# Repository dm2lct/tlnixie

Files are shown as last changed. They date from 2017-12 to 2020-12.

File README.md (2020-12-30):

# Schematics and PCB files for the Turmlabor nixie clock kit. 
# Attention: This is a old, buggy version! See the new design on https://github.com/ludwig1992/Nixieclock_kit

Feel free to build your own nixie clock from it.

Features:
  - IN14 nixie tubes but you can adapt many other nixie tubes even if it would not look great
  - ESP12e controller so you can make IoT with it and build your own botnet for world domination if you have enough clocks
  - DS3231 RTC for everyone who does not like IoT and does also not want to be enslaved from AI
  - WS2812B under each nixie tube to make them look more fancy
  - runs from a simple USB charger
  - you can program the controller with your Arduino IDE over USB

But in this version there are a few known issues:

  - wrong footprint of U201 and U202, it should be PQFP44, but of any reason we put TQFP44 on this board. You can solder it but it's not fun. 
  - wrong wiring of U403, you need to wire pin 10 and 11 to pin 18 and 19 and move VCC from pin 18 to pin 20.
  - the high voltage power supply does not work as good as it is supposed to be. This might be a problem with the low input voltage of about 5V

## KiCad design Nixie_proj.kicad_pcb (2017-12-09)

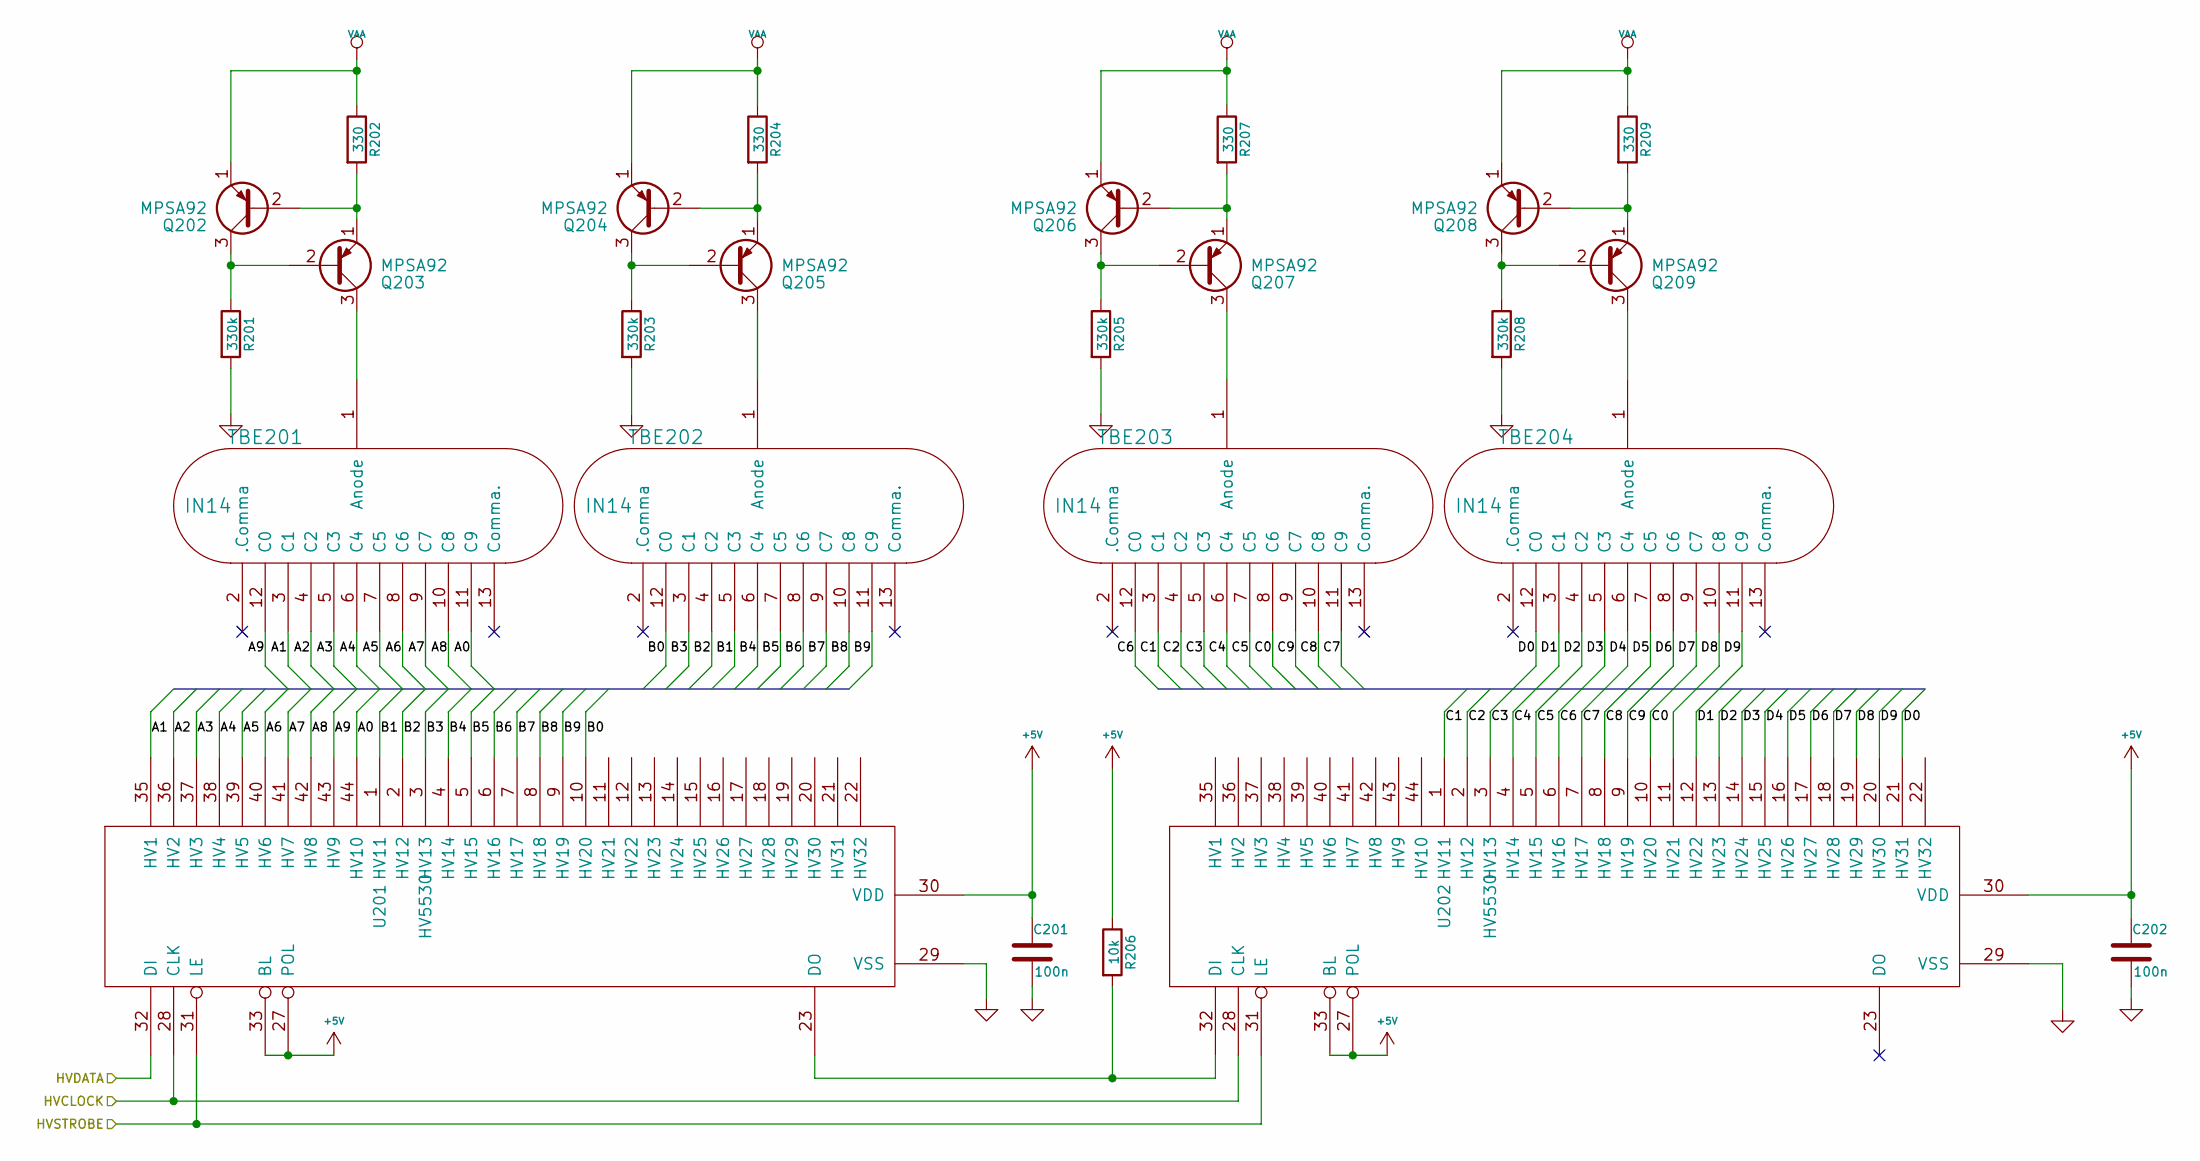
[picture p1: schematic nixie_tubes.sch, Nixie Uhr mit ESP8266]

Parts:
C201, C202: 100n; C_0805_HandSoldering
Q202, Q203, Q204, Q205, Q206, Q207, Q208, Q209: MPSA92; TO-92_Molded_Wide_Oval
R201, R203, R205, R208: 330k; R_Axial_DIN0207_L6.3mm_D2.5mm_P10.16mm_Horizontal
R202, R204, R207, R209: 330; R_Axial_DIN0207_L6.3mm_D2.5mm_P10.16mm_Horizontal
R206: 10k; R_0805_HandSoldering
TBE201, TBE202, TBE203, TBE204: IN14; IN-14-mod
U201, U202: HV5530; TQFP-44_10x10mm_Pitch0.8mm

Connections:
+5V: C201.1, C202.1, R206.1, U201.27 (POL), U201.30 (VDD), U201.33 (BL), U202.27 (POL), U202.30 (VDD), U202.33 (BL); also elsewhere on the board
/Microcontroller and clock/HVCLOCK: U201.28 (CLK), U202.28 (CLK); also elsewhere on the board
/Microcontroller and clock/HVDATA: U201.32 (DI); also elsewhere on the board
/Microcontroller and clock/HVSTROBE: U201.31 (LE), U202.31 (LE); also elsewhere on the board
/Tubes with drivers/A0: TBE201.11 (C9), U201.44 (HV10)
/Tubes with drivers/A1: TBE201.3 (C1), U201.35 (HV1)
/Tubes with drivers/A2: TBE201.4 (C2), U201.36 (HV2)
/Tubes with drivers/A3: TBE201.5 (C3), U201.37 (HV3)
/Tubes with drivers/A4: TBE201.6 (C4), U201.38 (HV4)
/Tubes with drivers/A5: TBE201.7 (C5), U201.39 (HV5)
/Tubes with drivers/A6: TBE201.8 (C6), U201.40 (HV6)
/Tubes with drivers/A7: TBE201.9 (C7), U201.41 (HV7)
/Tubes with drivers/A8: TBE201.10 (C8), U201.42 (HV8)
/Tubes with drivers/A9: TBE201.12 (C0), U201.43 (HV9)
/Tubes with drivers/B0: TBE202.12 (C0), U201.10 (HV20)
/Tubes with drivers/B1: TBE202.5 (C3), U201.1 (HV11)
/Tubes with drivers/B2: TBE202.4 (C2), U201.2 (HV12)
/Tubes with drivers/B3: TBE202.3 (C1), U201.3 (HV13)
/Tubes with drivers/B4: TBE202.6 (C4), U201.4 (HV14)
/Tubes with drivers/B5: TBE202.7 (C5), U201.5 (HV15)
/Tubes with drivers/B6: TBE202.8 (C6), U201.6 (HV16)
/Tubes with drivers/B7: TBE202.9 (C7), U201.7 (HV17)
/Tubes with drivers/B8: TBE202.10 (C8), U201.8 (HV18)
/Tubes with drivers/B9: TBE202.11 (C9), U201.9 (HV19)
/Tubes with drivers/C0: TBE203.8 (C6), U202.10 (HV20)
/Tubes with drivers/C1: TBE203.3 (C1), U202.1 (HV11)
/Tubes with drivers/C2: TBE203.4 (C2), U202.2 (HV12)
/Tubes with drivers/C3: TBE203.5 (C3), U202.3 (HV13)
/Tubes with drivers/C4: TBE203.6 (C4), U202.4 (HV14)
/Tubes with drivers/C5: TBE203.7 (C5), U202.5 (HV15)
/Tubes with drivers/C6: TBE203.12 (C0), U202.6 (HV16)
/Tubes with drivers/C7: TBE203.11 (C9), U202.7 (HV17)
/Tubes with drivers/C8: TBE203.10 (C8), U202.8 (HV18)
/Tubes with drivers/C9: TBE203.9 (C7), U202.9 (HV19)
/Tubes with drivers/D0: TBE204.12 (C0), U202.21 (HV31)
/Tubes with drivers/D1: TBE204.3 (C1), U202.12 (HV22)
/Tubes with drivers/D2: TBE204.4 (C2), U202.13 (HV23)
/Tubes with drivers/D3: TBE204.5 (C3), U202.14 (HV24)
/Tubes with drivers/D4: TBE204.6 (C4), U202.15 (HV25)
/Tubes with drivers/D5: TBE204.7 (C5), U202.16 (HV26)
/Tubes with drivers/D6: TBE204.8 (C6), U202.17 (HV27)
/Tubes with drivers/D7: TBE204.9 (C7), U202.18 (HV28)
/Tubes with drivers/D8: TBE204.10 (C8), U202.19 (HV29)
/Tubes with drivers/D9: TBE204.11 (C9), U202.20 (HV30)
GND: C201.2, C202.2, R201.2, R203.2, R205.2, R208.2, U201.29 (VSS), U202.29 (VSS); also elsewhere on the board
unnamed: Q202.2 (B), Q203.1 (E), R202.2
unnamed: Q202.3 (C), Q203.2 (B), R201.1
unnamed: Q203.3 (C), TBE201.1 (Anode)
unnamed: Q204.2 (B), Q205.1 (E), R204.2
unnamed: Q204.3 (C), Q205.2 (B), R203.1
unnamed: Q205.3 (C), TBE202.1 (Anode)
unnamed: Q206.2 (B), Q207.1 (E), R207.2
unnamed: Q206.3 (C), Q207.2 (B), R205.1
unnamed: Q207.3 (C), TBE203.1 (Anode)
unnamed: Q208.2 (B), Q209.1 (E), R209.2
unnamed: Q208.3 (C), Q209.2 (B), R208.1
unnamed: Q209.3 (C), TBE204.1 (Anode)
unnamed: R206.2, U201.23 (DO), U202.32 (DI)
VAA: Q202.1 (E), Q204.1 (E), Q206.1 (E), Q208.1 (E), R202.1, R204.1, R207.1, R209.1; also elsewhere on the board

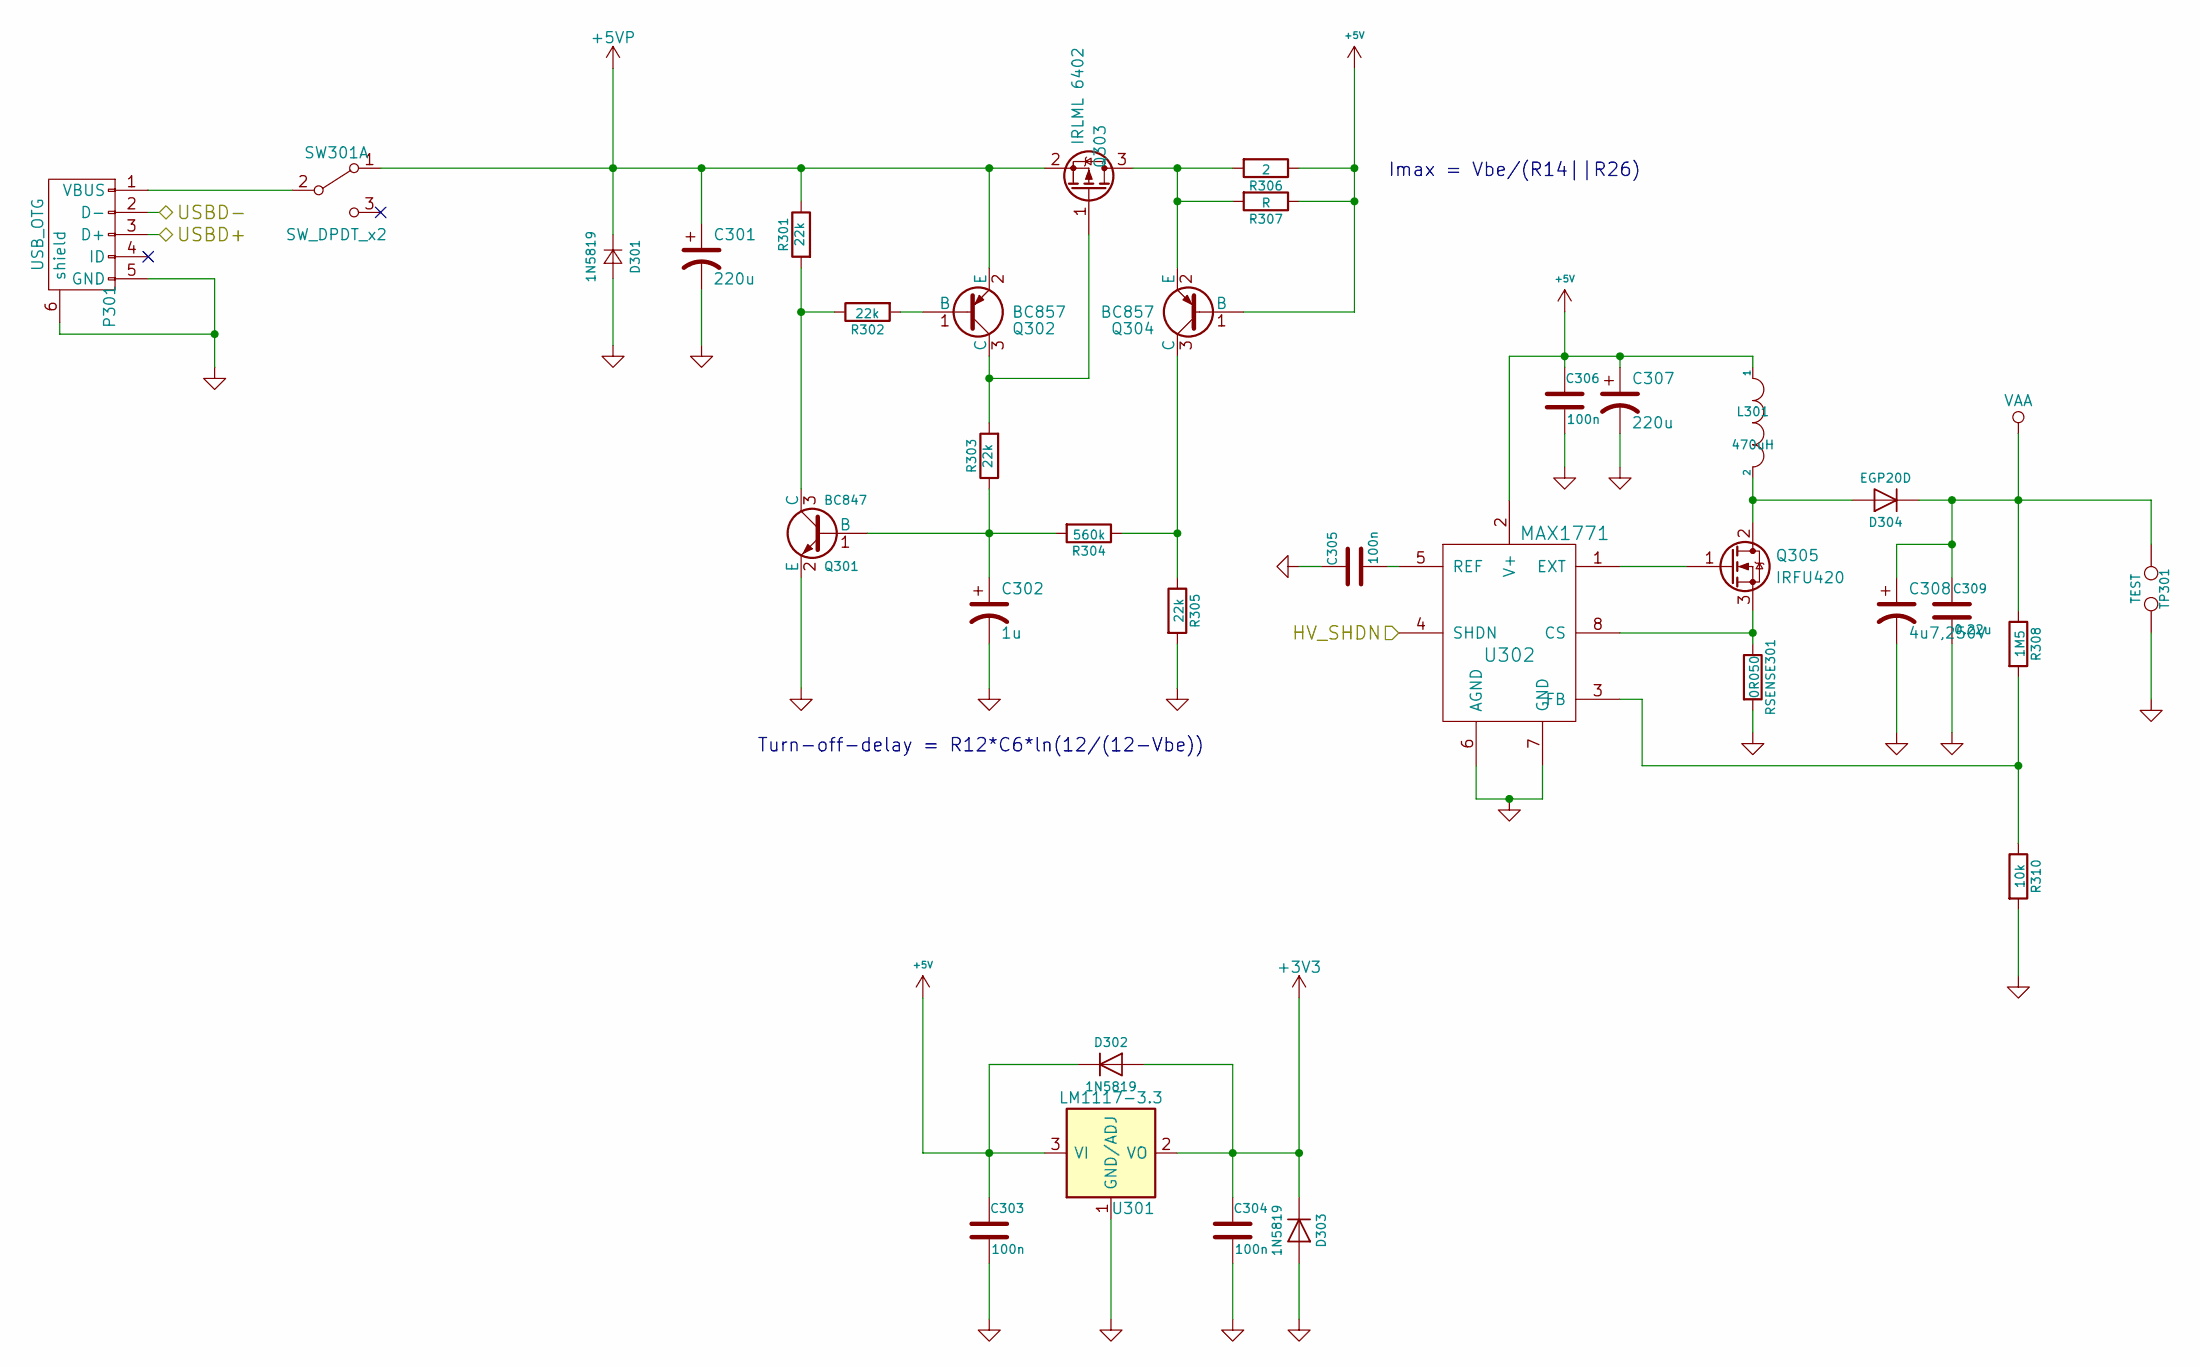
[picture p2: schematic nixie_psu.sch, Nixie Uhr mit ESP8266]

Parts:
C301, C307: 220u; CP_Elec_6.3x7.7
C302: 1u; CP_Elec_4x5.7
C303, C304, C305, C306: 100n; C_0805_HandSoldering
C308: 4u7,250V; CP_Radial_D10.0mm_P7.50mm
C309: 0.22u; C_Rect_L13.0mm_W6.0mm_P10.00mm_FKS3_FKP3_MKS4
D301, D302, D303: 1N5819; D_MiniMELF_Handsoldering
D304: EGP20D; D_MELF-RM10_Universal_Handsoldering
L301: 470uH; L_Radial_D8.7mm_P5.00mm_Fastron_07HCP
P301: USB_OTG; USB_Mini-B
Q301: BC847; SOT-23W_Handsoldering
Q302, Q304: BC857; SOT-23W_Handsoldering
Q303: IRLML 6402; SOT-23W_Handsoldering
Q305: IRFU420; TO-252-3_TabPin4
R301, R302, R303, R305: 22k; R_0805_HandSoldering
R304: 560k; R_0805_HandSoldering
R306: 2; R_1210_HandSoldering
R307: R; R_1210_HandSoldering
R308: 1M5; R_0805_HandSoldering
R310: 10k; R_0805_HandSoldering
RSENSE301: 0R050; R_1210_HandSoldering
SW301: SW_DPDT_x2; SW_CuK_OS102011MA1QN1_SPDT_Angled
TP301: TEST; R_1210_HandSoldering
U301: LM1117-3.3; TO-252-2
U302: MAX1771; DIP-8_W7.62mm_LongPads

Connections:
+3V3: C304.1, D302.2 (A), D303.1 (K), U301.2 (VO), U301.4 (VO); also elsewhere on the board
+5V: C303.1, C306.1, C307.1, D302.1 (K), L301.1, Q304.1 (B), R306.1, R307.1, U301.3 (VI), U302.2 (V+); also elsewhere on the board
+5VP: C301.1, D301.1 (K), Q302.2 (E), Q303.2 (S), R301.1, SW301.1 (A)
/Microcontroller and clock/HV_SHDN: U302.4 (SHDN); also elsewhere on the board
/Microcontroller and clock/USBD+: P301.3 (D+); also elsewhere on the board
/Microcontroller and clock/USBD-: P301.2 (D-); also elsewhere on the board
GND: C301.2, C302.2, C303.2, C304.2, C305.1, C306.2, C307.2, C308.2, C309.2, D301.2 (A), D303.2 (A), P301.5 (GND), P301.6 (shield), Q301.2 (E), R305.2, R310.2, RSENSE301.2, TP301.2, U301.1 (GND/ADJ), U302.6 (AGND), U302.7 (GND); also elsewhere on the board
unnamed: C302.1, Q301.1 (B), R303.1, R304.2
unnamed: C305.2, U302.5 (REF)
unnamed: D304.2 (A), L301.2, Q305.2 (D)
unnamed: P301.1 (VBUS), SW301.2 (B)
unnamed: Q301.3 (C), R301.2, R302.1
unnamed: Q302.1 (B), R302.2
unnamed: Q302.3 (C), Q303.1 (G), R303.2
unnamed: Q303.3 (D), Q304.2 (E), R306.2, R307.2
unnamed: Q304.3 (C), R304.1, R305.1
unnamed: Q305.1 (G), U302.1 (EXT)
unnamed: Q305.3 (S), RSENSE301.1, U302.8 (CS)
unnamed: R308.2, R310.1, U302.3 (FB)
VAA: C308.1, C309.1, D304.1 (K), R308.1, TP301.1; also elsewhere on the board

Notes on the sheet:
Imax = Vbe/(R14||R26)
Turn-off-delay = R12*C6*ln(12/(12-Vbe))

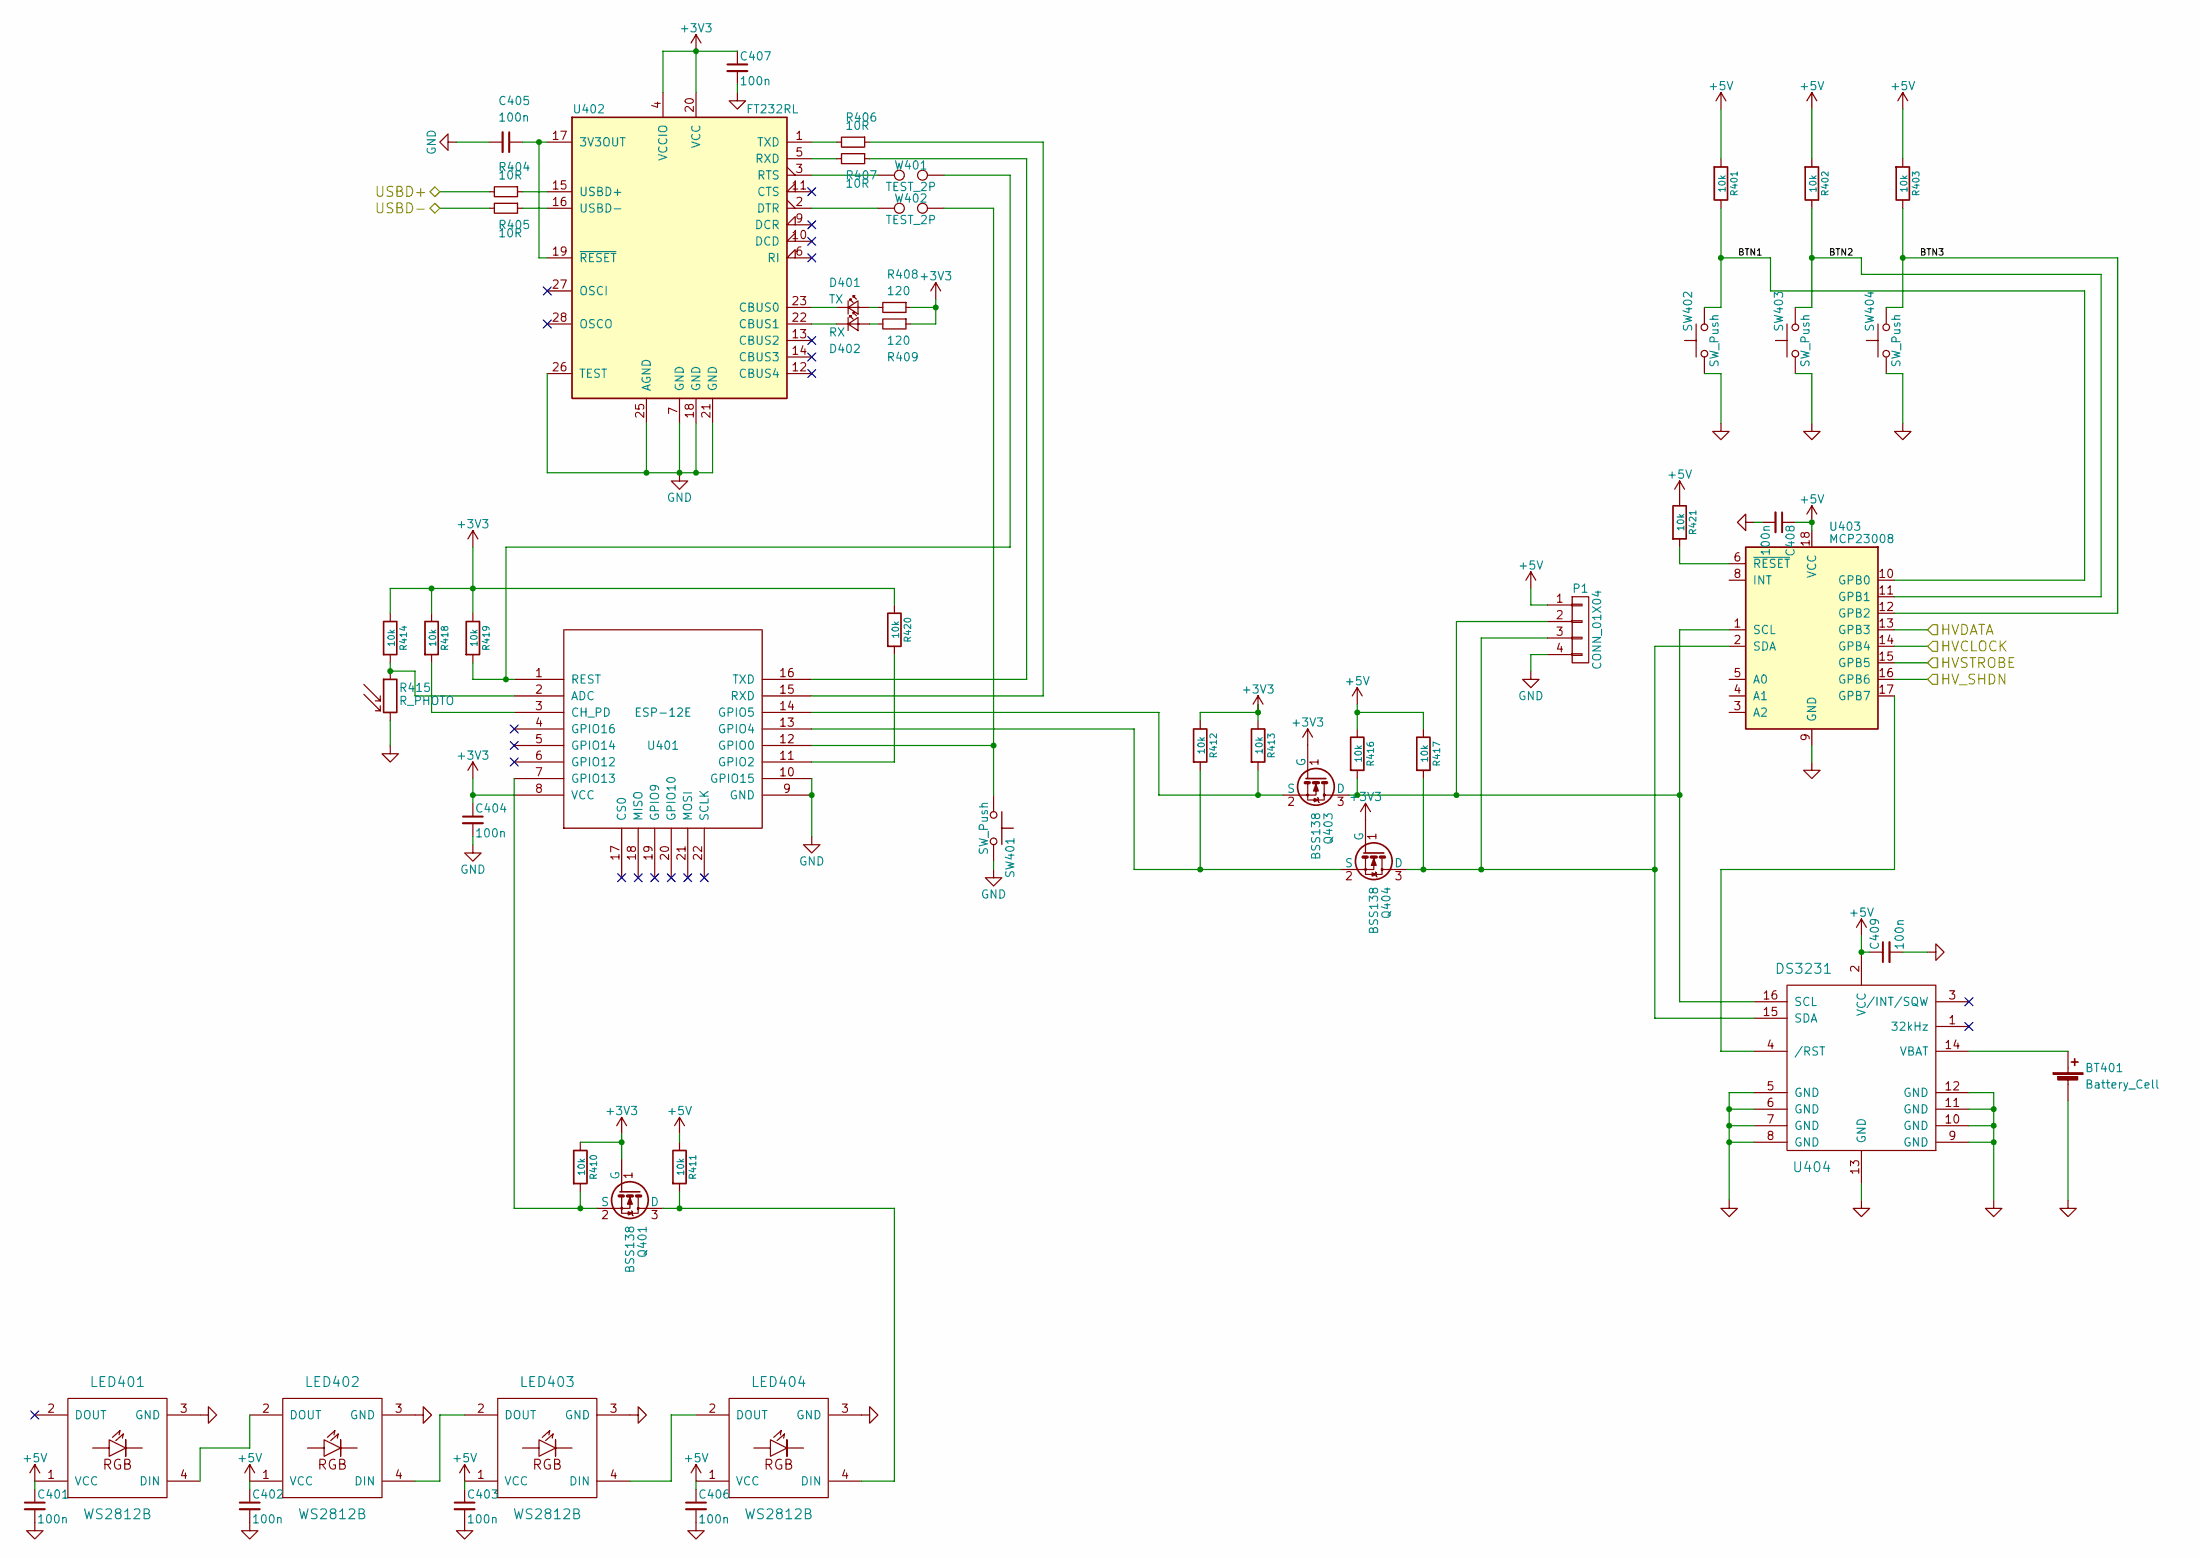
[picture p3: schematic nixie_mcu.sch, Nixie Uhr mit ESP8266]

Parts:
BT401: Battery_Cell; Keystone_3034_1x20mm-CoinCell
C401, C402, C403, C404, C405, C406, C407, C408, C409: 100n; C_0805_HandSoldering
D401: TX; LED_0805_HandSoldering
D402: RX; LED_0805_HandSoldering
LED401, LED402, LED403, LED404: WS2812B
P1: CONN_01X04; Pin_Header_Straight_1x04_Pitch2.54mm
Q401, Q403, Q404: BSS138; SOT-23W_Handsoldering
R401, R402, R403, R410, R411, R412, R413, R414, R416, R417, R418, R419, R420, R421: 10k; R_0805_HandSoldering
R404, R405, R406, R407: 10R; R_0805_HandSoldering
R408, R409: 120; R_0805_HandSoldering
R415: R_PHOTO; R_Axial_DIN0207_L6.3mm_D2.5mm_P5.08mm_Vertical
SW401: SW_Push; SW_PUSH_6mm_h4.3mm
SW402, SW403, SW404: SW_Push; SW_Tactile_SPST_Angled_PTS645Vx39-2LFS
U401: ESP-12E; ESP-12E_SMD
U402: FT232RL; SSOP-28_5.3x10.2mm_Pitch0.65mm
U403: MCP23008; SSOP-20_5.3x7.2mm_Pitch0.65mm
U404: DS3231; SOIC-16W_7.5x10.3mm_Pitch1.27mm
W401, W402: TEST_2P; R_0805_HandSoldering

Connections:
+3V3: C404.1, C407.1, Q401.1 (G), Q403.1 (G), Q404.1 (G), R408.1, R409.1, R410.1, R412.1, R413.1, R414.1, R418.1, R419.1, R420.1, U401.8 (VCC), U402.4 (VCCIO), U402.20 (VCC); also elsewhere on the board
+5V: C401.1, C402.1, C403.1, C406.1, C408.1, C409.1, LED401.1 (VCC), LED402.1 (VCC), LED403.1 (VCC), LED404.1 (VCC), P1.1, R401.2, R402.2, R403.2, R411.1, R416.1, R417.1, R421.1, U403.18 (VCC), U404.2 (VCC); also elsewhere on the board
/Microcontroller and clock/BTN1: R401.1, SW402.2, U403.10 (GPB0)
/Microcontroller and clock/BTN2: R402.1, SW403.2, U403.11 (GPB1)
/Microcontroller and clock/BTN3: R403.1, SW404.2, U403.12 (GPB2)
/Microcontroller and clock/HVCLOCK: U403.14 (GPB4); also elsewhere on the board
/Microcontroller and clock/HVDATA: U403.13 (GPB3); also elsewhere on the board
/Microcontroller and clock/HVSTROBE: U403.15 (GPB5); also elsewhere on the board
/Microcontroller and clock/HV_SHDN: U403.16 (GPB6); also elsewhere on the board
/Microcontroller and clock/USBD+: R404.2; also elsewhere on the board
/Microcontroller and clock/USBD-: R405.2; also elsewhere on the board
GND: BT401.2 (-), C401.2, C402.2, C403.2, C404.2, C405.2, C406.2, C407.2, C408.2, C409.2, LED401.3 (GND), LED402.3 (GND), LED403.3 (GND), LED404.3 (GND), P1.4, R415.2, SW401.2, SW402.1, SW403.1, SW404.1, U401.9 (GND), U401.10 (GPIO15), U402.7 (GND), U402.18 (GND), U402.21 (GND), U402.25 (AGND), U402.26 (TEST), U403.9 (GND), U404.5 (GND), U404.6 (GND), U404.7 (GND), U404.8 (GND), U404.9 (GND), U404.10 (GND), U404.11 (GND), U404.12 (GND), U404.13 (GND); also elsewhere on the board
unnamed 53: BT401.1 (+), U404.14 (VBAT); also elsewhere on the board
unnamed: C405.1, U402.17 (3V3OUT), U402.19 (~RESET~)
unnamed 58: D401.1 (K), U402.23 (CBUS0); also elsewhere on the board
unnamed 59: D401.2 (A), R408.2; also elsewhere on the board
unnamed 60: D402.1 (K), U402.22 (CBUS1); also elsewhere on the board
unnamed 61: D402.2 (A), R409.2; also elsewhere on the board
unnamed: LED401.4 (DIN), LED402.2 (DOUT)
unnamed: LED402.4 (DIN), LED403.2 (DOUT)
unnamed: LED403.4 (DIN), LED404.2 (DOUT)
unnamed: LED404.4 (DIN), Q401.3 (D), R411.2
unnamed 66: P1.2, Q403.3 (D), R416.2, U403.1 (SCL), U404.16 (SCL); also elsewhere on the board
unnamed 67: P1.3, Q404.3 (D), R417.2, U403.2 (SDA), U404.15 (SDA); also elsewhere on the board
unnamed: Q401.2 (S), R410.2, U401.7 (GPIO13)
unnamed: Q403.2 (S), R413.2, U401.14 (GPIO5)
unnamed: Q404.2 (S), R412.2, U401.13 (GPIO4)
unnamed: R404.1, U402.15 (USBD+)
unnamed: R405.1, U402.16 (USBD-)
unnamed: R406.1, U401.15 (RXD)
unnamed: R406.2, U402.1 (TXD)
unnamed: R407.1, U401.16 (TXD)
unnamed: R407.2, U402.5 (RXD)
unnamed: R414.2, R415.1, U401.2 (ADC)
unnamed: R418.2, U401.3 (CH_PD)
unnamed: R419.2, U401.1 (REST), W401.2
unnamed: R420.2, U401.11 (GPIO2)
unnamed: R421.2, U403.6 (~RESET)
unnamed 104: SW401.1, U401.12 (GPIO0), W402.2; also elsewhere on the board
unnamed: U402.2 (DTR), W402.1
unnamed: U402.3 (RTS), W401.1
unnamed: U403.17 (GPB7), U404.4 (/RST)

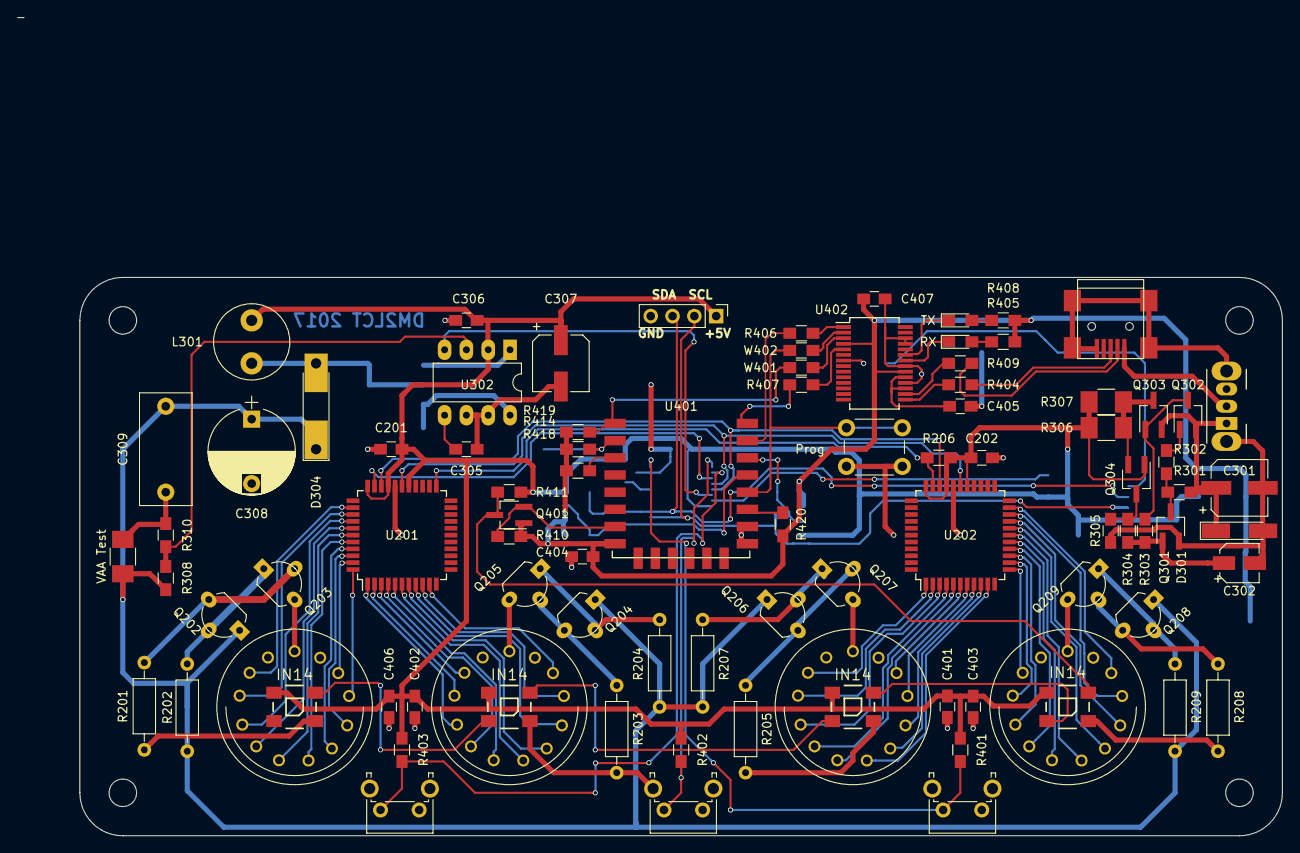
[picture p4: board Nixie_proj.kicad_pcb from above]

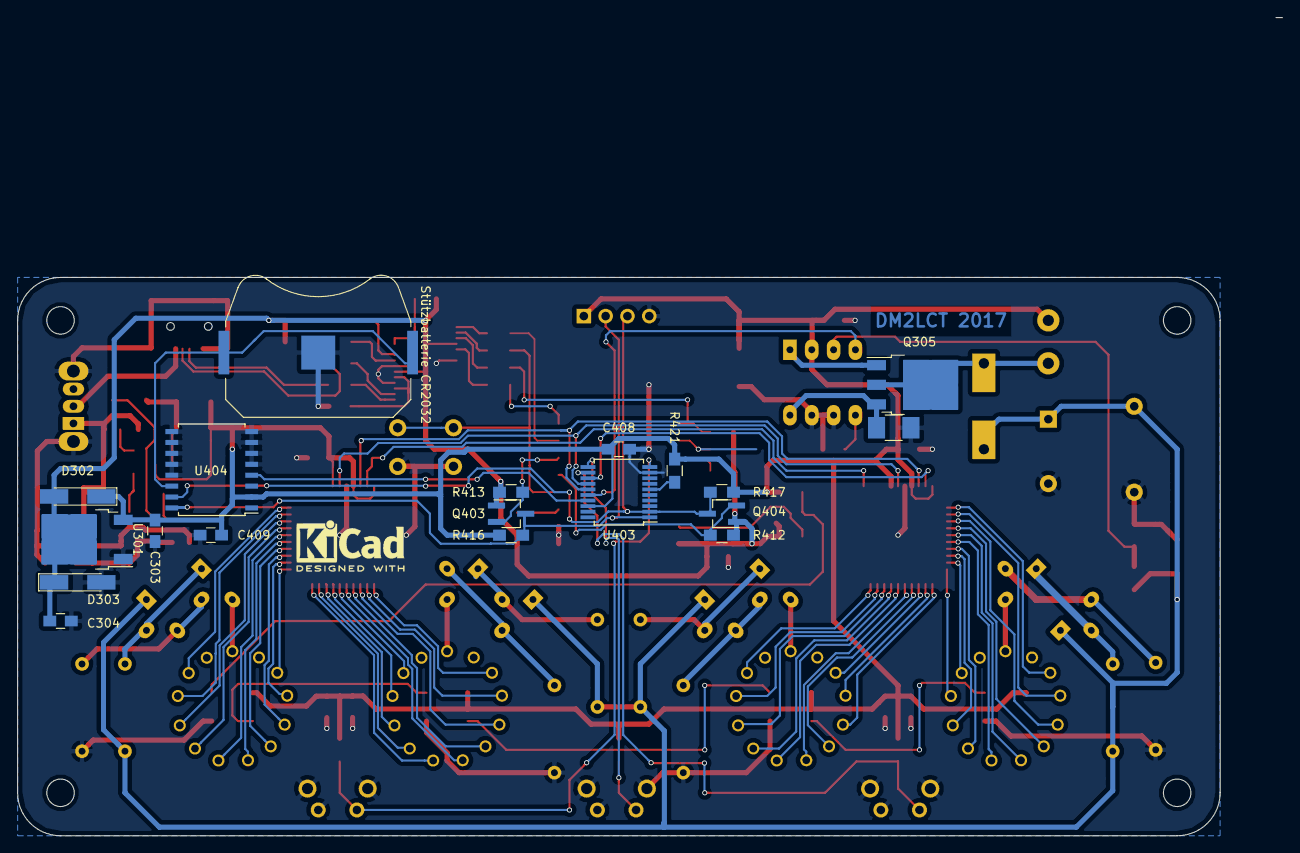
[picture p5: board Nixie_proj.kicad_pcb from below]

Board: 2 copper layers, 140.0 x 65.0 mm, 109 parts (19 on the bottom side), 109 nets.

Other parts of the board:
Prog: SW_Push; SW_PUSH_6mm_h4.3mm
RX: RX; LED_0805_HandSoldering
SPI Interface: CONN_01X04; Pin_Header_Straight_1x04_Pitch2.54mm
Stützbatterie CR2032: Battery_Cell; Keystone_3034_1x20mm-CoinCell
TX: TX; LED_0805_HandSoldering
VAA Test: TEST; R_1210_HandSoldering

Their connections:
+5V: SPI Interface.1; also elsewhere on the board
GND: Prog.2, SPI Interface.4, Stützbatterie CR2032.2, VAA Test.2; also elsewhere on the board
unnamed 53: Stützbatterie CR2032.1; also elsewhere on the board
unnamed 58: TX.1; also elsewhere on the board
unnamed 59: TX.2; also elsewhere on the board
unnamed 60: RX.1; also elsewhere on the board
unnamed 61: RX.2; also elsewhere on the board
unnamed 66: SPI Interface.2; also elsewhere on the board
unnamed 67: SPI Interface.3; also elsewhere on the board
unnamed 104: Prog.1; also elsewhere on the board
VAA: VAA Test.1; also elsewhere on the board
